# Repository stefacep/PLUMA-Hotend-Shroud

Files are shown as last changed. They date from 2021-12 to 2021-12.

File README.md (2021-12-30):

# PLUMA-Hotend-Shroud
A seamless solution for integrating a mk8 class hotend or an NF-Crazy Plus hotend with a bmg extruder on linear rail or v-wheel equipped ender 3, ender 3 pro and ender 3 V2 Printers

## Possible Configurations:
- Stock(Mk8,  Microswiss) Hotend, Stock Body or MGN12 Body Chassis, ABL,4020 or 5015 Fang
- NF Crazy Plus, MGN12 Body Chassis, ABL, 4020 or 5015 Fang

The BOM on the pdf is for the Stock configuration, the BOM for the alternate configuration will come soon

## 
In early-mid 2020, upon looking for potential solutions, i have not found a solution for the ender 3 printer that integrates both a microswiss/mk8 class hotend with a bmg hotend is not invasive to the point that a hotend swap is required nor a translation of the y axis extrusion to recoup the lost build space.

As a result the product was designed and prototyped in July 2020 and tested with several iterations for the latter part of 2020 and 2021, with minimal tweaks to increase useability, durability, reduce weight and increase part cooling effectiveness

In early 2021, upon switching to a NF-Crazy hotend and an MGN12 motion system, PLUMA was derived to support both architectures with the main chassis being able to directly interface with the linear rail carriage without the original aluminum x plate, therefore reducing complexity and weight

The original fang that supports a 4020 was also derived to support a 5015 in mid 2021

##
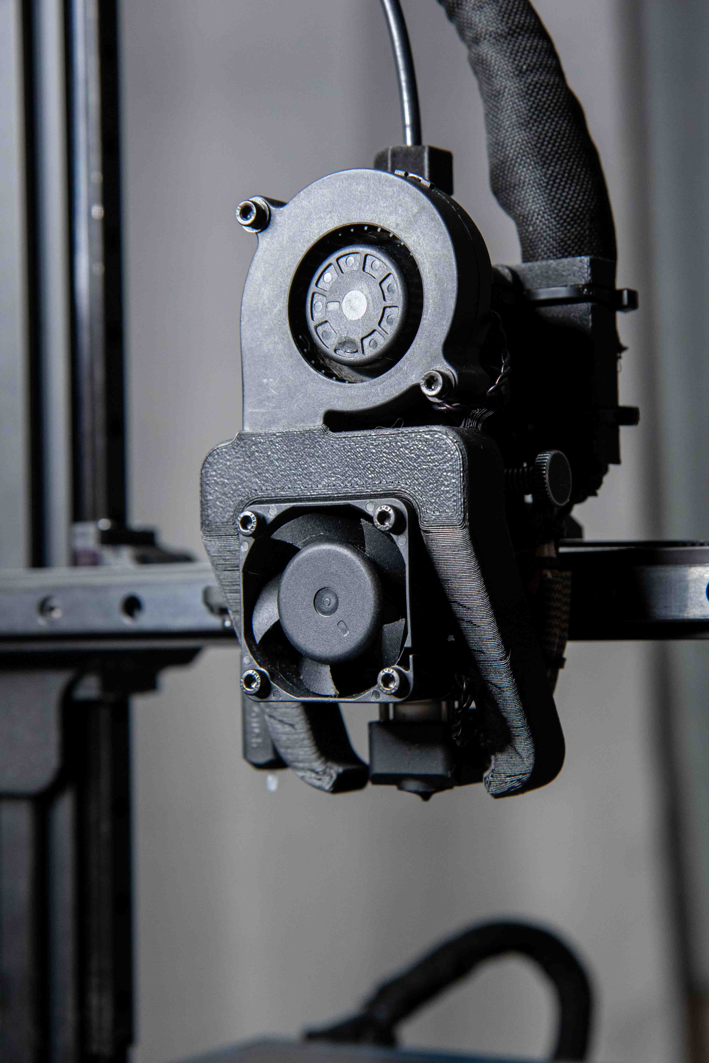
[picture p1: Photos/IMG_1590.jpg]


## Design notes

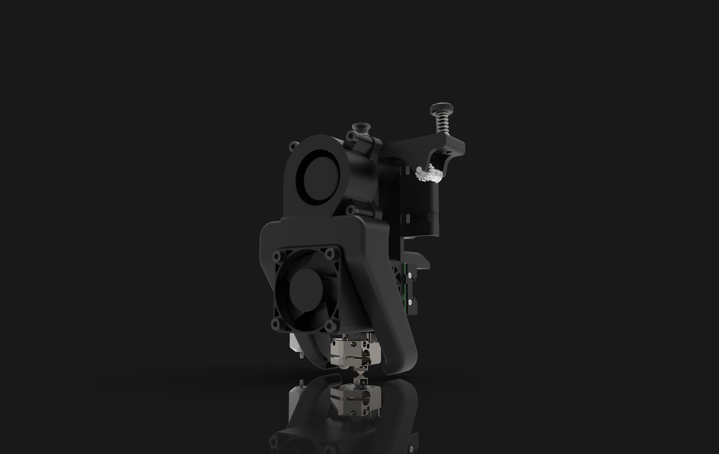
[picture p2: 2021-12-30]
Photos/PLUMA-1.4.jpg

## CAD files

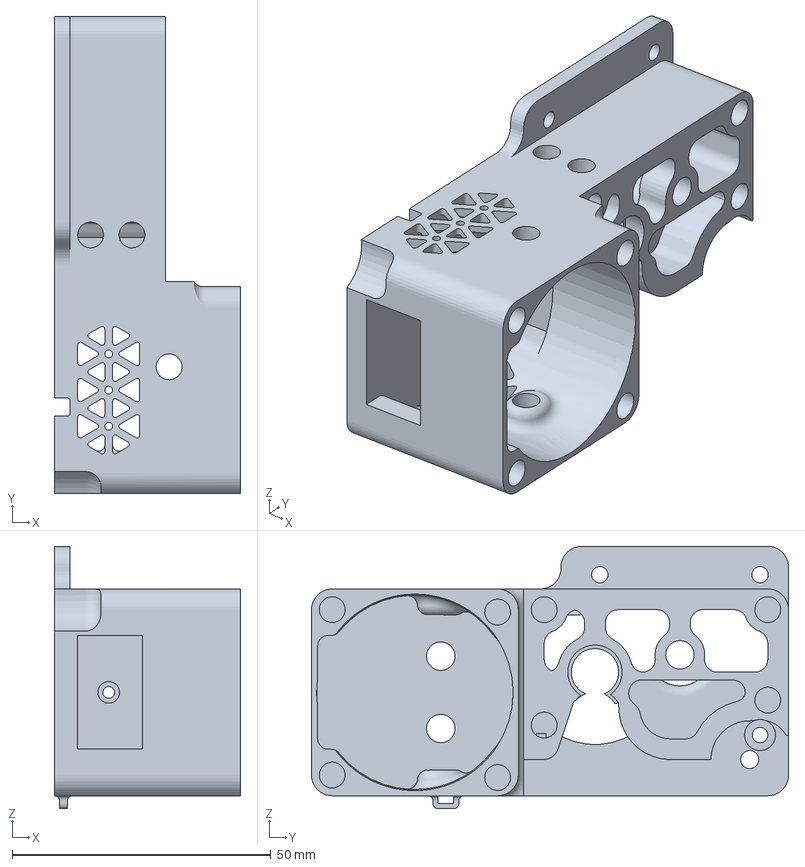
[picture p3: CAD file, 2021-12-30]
3MF/Main Body/Main Body(Stock Carriage).3MF
36.0 x 92.3 x 50.8 mm

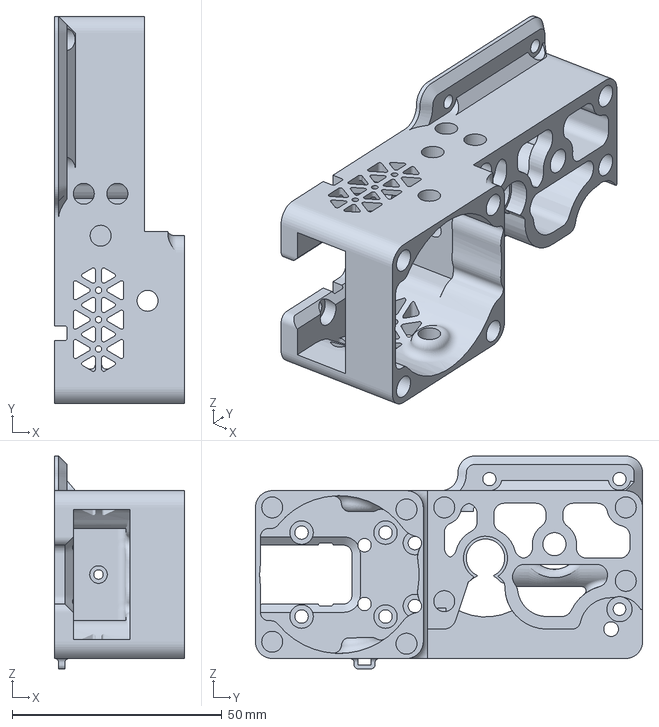
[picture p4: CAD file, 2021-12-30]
3MF/Main Body/Main Body(NF Crazy Plus-MGN12).3MF
31.0 x 92.2 x 50.8 mm

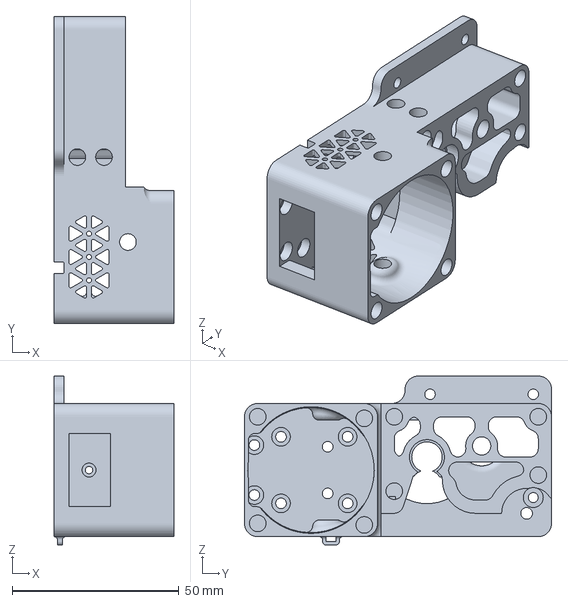
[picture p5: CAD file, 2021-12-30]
3MF/Main Body/Main Body(MGN12 Mount).3MF
36.0 x 92.2 x 50.8 mm

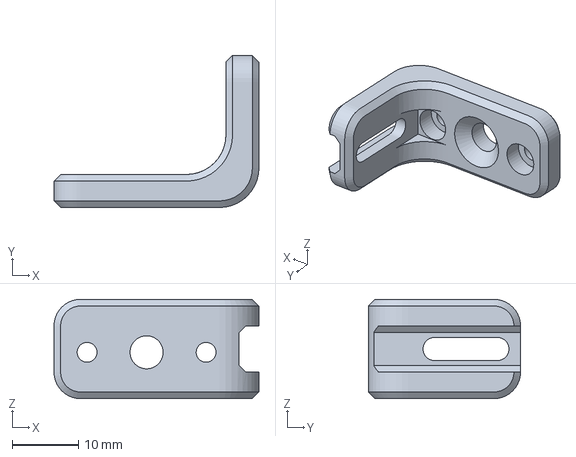
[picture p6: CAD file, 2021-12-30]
3MF/ABL/BLtouch Adapter.3MF
31.0 x 23.0 x 15.0 mm

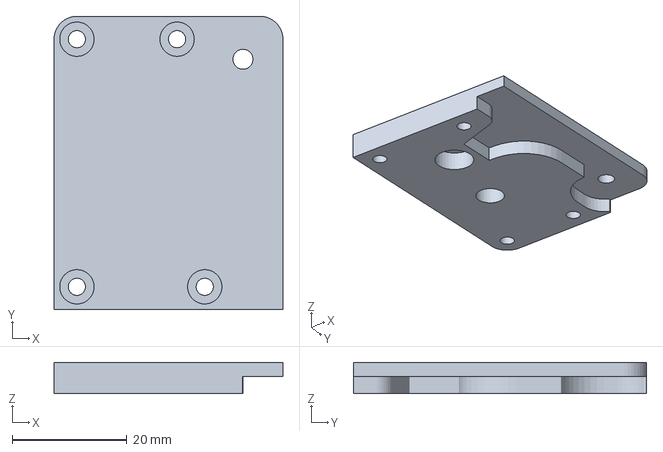
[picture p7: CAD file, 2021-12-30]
3MF/Main Body/Front Extruder Cover.3MF
40.0 x 51.2 x 5.50 mm

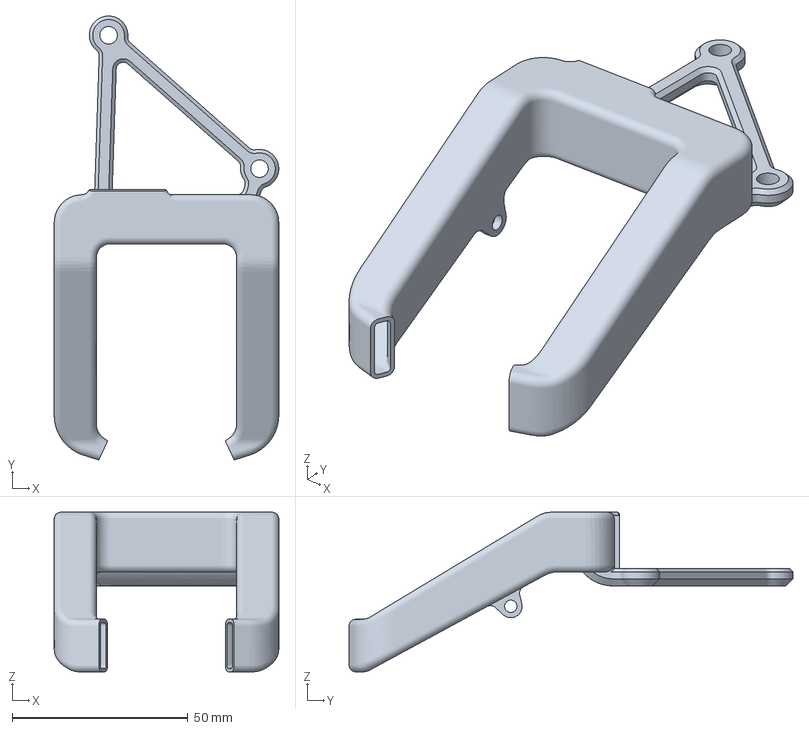
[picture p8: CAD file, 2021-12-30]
3MF/Part Cooling/Part Cooling Fang(5015).3MF
64.0 x 126.5 x 45.5 mm

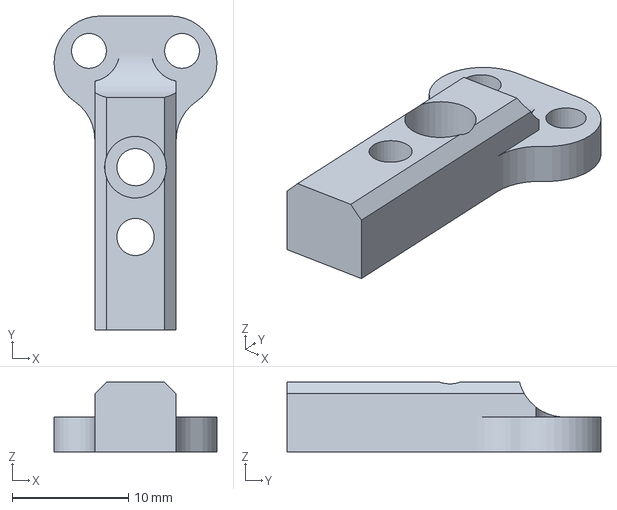
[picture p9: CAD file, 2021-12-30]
3MF/ABL/ABL Mount.3MF
14.0 x 27.0 x 6.00 mm

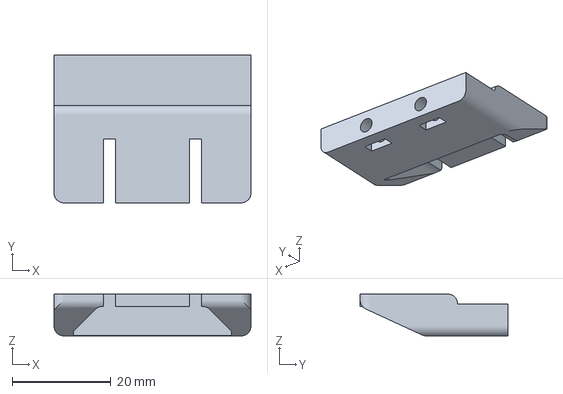
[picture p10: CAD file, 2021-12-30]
3MF/Main Body/MGN12 Belt mount.3MF
40.0 x 30.0 x 8.50 mm

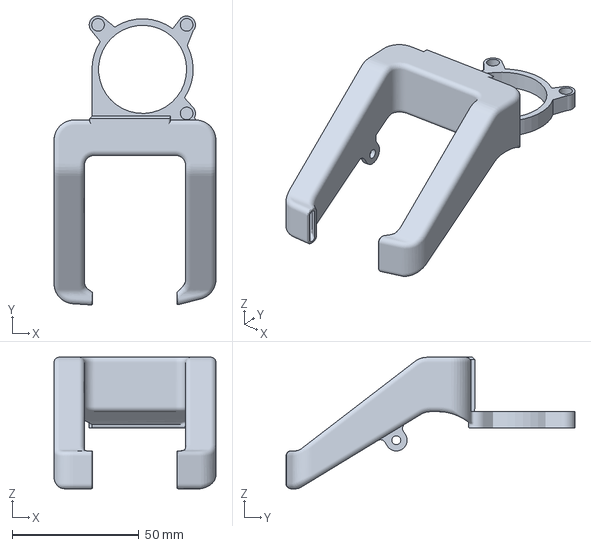
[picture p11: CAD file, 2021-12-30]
3MF/Part Cooling/Part Cooling Fang(4020 Radial).3MF
64.0 x 114.2 x 52.0 mm

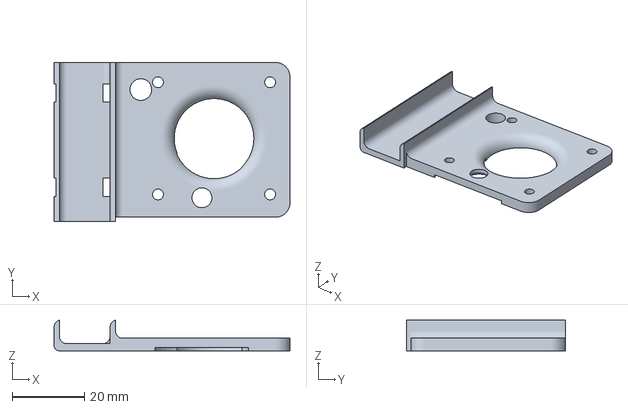
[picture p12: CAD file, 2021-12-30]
3MF/Main Body/Extruder Rear Cover.3MF
65.3 x 44.0 x 8.50 mm

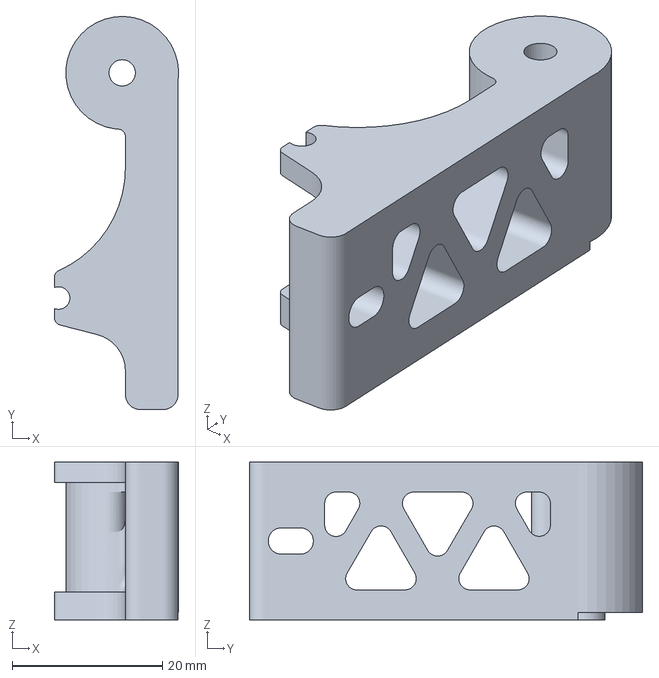
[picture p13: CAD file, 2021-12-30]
3MF/Main Body/Tensioner Arm.3MF
16.5 x 52.2 x 21.0 mm

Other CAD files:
3MF/Main Body/Main Body(Mosquito_NF Crazy - MGN12).3MF

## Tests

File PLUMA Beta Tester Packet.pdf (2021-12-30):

# Beta Tester’s Packet

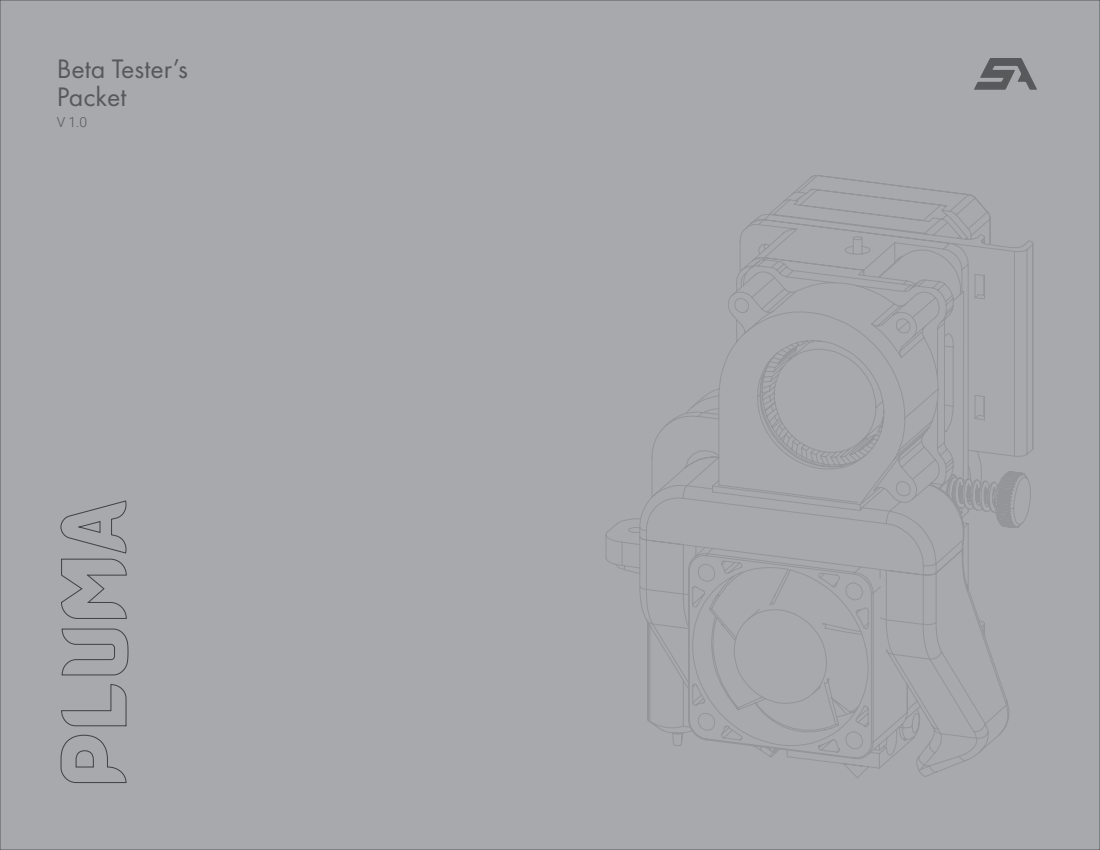
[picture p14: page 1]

# Initial Steps

Thanks for taking interest in the Pluma hotend shroud, as the product is currently in development, assembly and troubleshooting documentation is in development, so as a supplement, im giving this information packet to inform you of some important things.

Main Body | 1
Tensioner Arm | 1
Extruder Front Cover | 1
Extruder Rear Cover | 1
Part Cooling Fang | 1
Auto Bed Levelling Support³ | 1
BLTouch Mount³ | 1
M3 x 16 SHCS | 3
M3 x 25 SHCS | 4
M3 X 5 X 5 Heat Insert⁴ | 8
M3 Nut | 3
4020 24V Radial Fan | 1
4020 24V Axial Fan¹ | 1
BLTouch³ | 1
NEMA 17 0.9 Pancake | 1
X Carriage Plate Assembly | 1
4010 24V Axial Fan¹ | 1
Hotend Assembly² | 1

# Bill of Materials

A list of materials you will need to complete the hotend shroud; what kind,
how many do you need. Specific prices and supplier used is not listed due
to factors such as availability, continuity and regional variations.
Printed | Stock
Bondtech Gear Kit | 1
Bondtech Shaft Assembly | 1
Bondtech Motor Pinion | 1
MR85 ZZ Bearing | 2

## Non-printed and non-stock

1M BLTouch Extension Cable³ | 1
0.5 M Stepper Motor Cable | 1
M6 PTFE Fitting | 1
Bondtech Tensioner Screw | 1
M3 x 27 SHCS | 1

1 -4020 24V Axial Fan is not needed if you intend to use the stock fan, but also have to use M3 x 12 bolts instead of the M3 x 25 bolts listed.
2 - A microswiss or similar all metal hotend that uses the stock mounting is also compatible.
3 -Only needed if Auto Bed Levelling is used.
4 4 Inch Zipties (1 Bag) | 1 | -(thread size x outer diameter x length)
M3 x 6 SHCS | 9
M3 x 8 SHCS | 5
M3 X 5 X 3 Heat Insert⁴ | 4

Figure 1: M3 x 5 x 3 insert location in the main body

M3 X 5 X 3 Insert

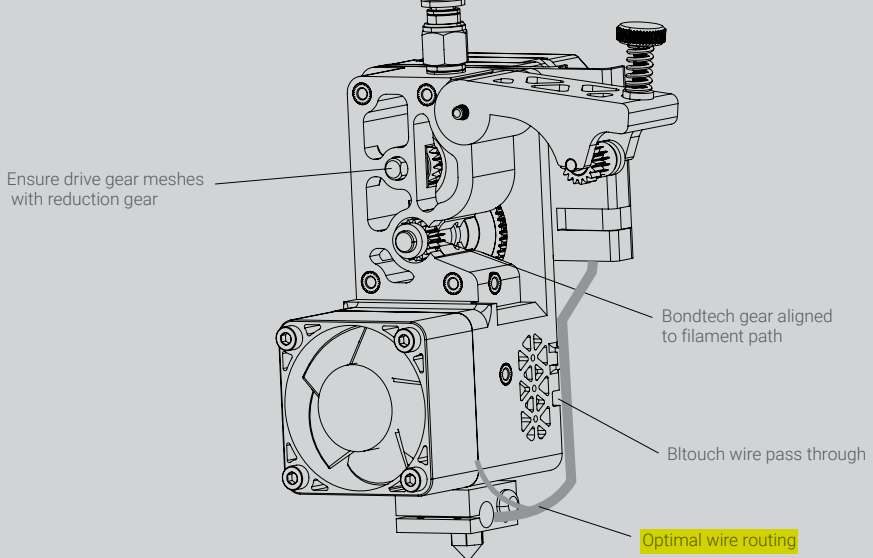
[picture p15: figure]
Bondtech gear aligned to filament path; Bltouch wire pass through; Optimal wire routing; Ensure drive gear meshes with reduction gear

Figure 2: General Assembly Notes

# General Information

Just some information to clarify some expected difficulties in assembly, if you have any questions, please contact me at contact.sacepcion@gmail.com

## Insert locations

all M3 x 5 x 5 inserts go inside the main body except for the location shown in figure 1, which require an M3 x 5 x 3 insert. the rest of the M3 x 5 x 3 inserts go to the fan mount location in the part cooling fang

## Hotend to shroud Bowden tube

the hotend to shroud bowden distance is currently 28.7 mm for the microswiss and unknown for the stock hotend, will require guess and check.

## 0.5 meter stepper Cable

The stepper cable outlined in the BOM is intended to be spliced into the existing extruder stepper cable.

## SHCS Screw locations

M3 x 6 - Auto bed levelling support, front cover and part cooling fang M3 x 8 - Extruder screws, bltouch mount
M3 x 16 - Part cooling fan
M3 x 25 - 4020 axial fan, substitute with M3 x 12 if using a 4010 axial
M3 x 27 - since this is an odd size, you can cut an M3 x 30+ bolt to 27mm instead, intended for use on the tensioner hinge
M3 nut - Bltouch Mount and auto bed levelling support

## Print Settings

General - up to 0.32mm layer height, at least 4 walls and 30-50% infill Material - PETG/ABS or Equivalent (PLA not recommended) Supports - Yes for the part cooling fang and main body
